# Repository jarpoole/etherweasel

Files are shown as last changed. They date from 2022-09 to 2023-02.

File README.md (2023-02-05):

# EtherWeasel

A proof-of-concept for a hardware man-in-the-middle attack on an Ethernet network. For demonstration purposes this repository provides an implementation of a DNS cache poisoning attack which can edit DNS requests and responses in realtime to trick web clients into connecting to the wrong ip addresses.

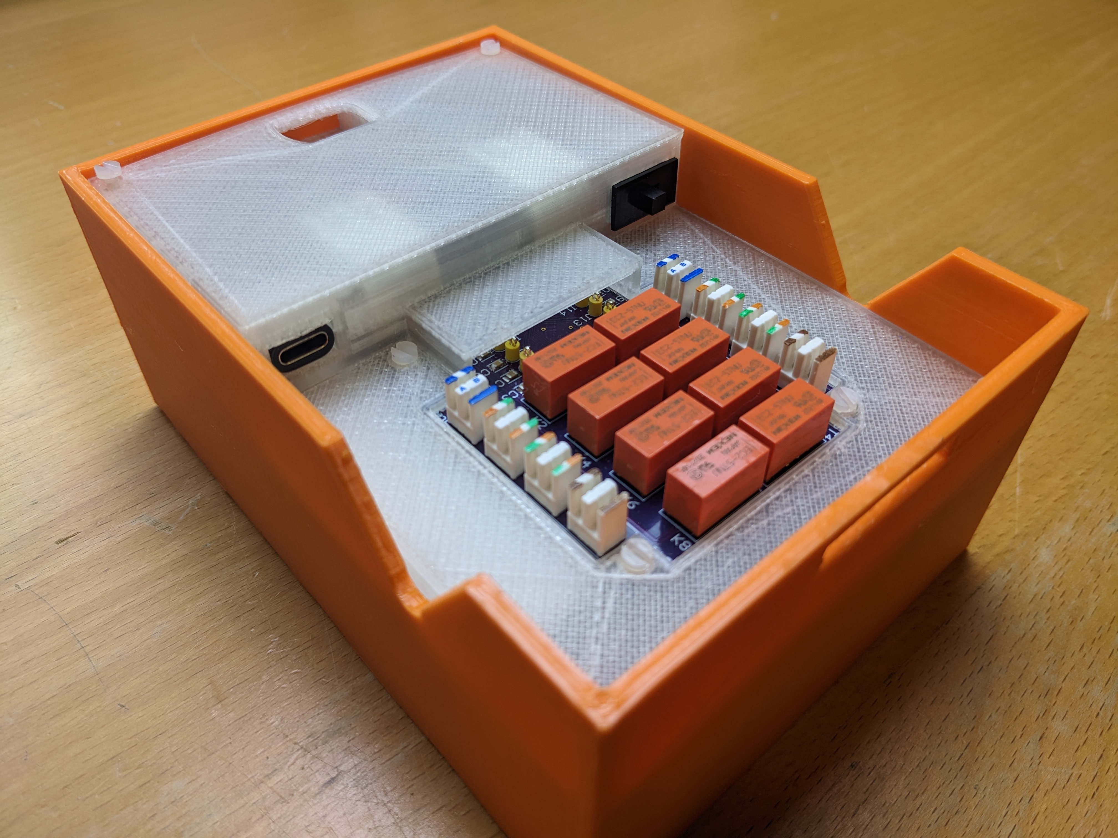
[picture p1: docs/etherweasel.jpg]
etherweasel


## Video

Watch the video that goes with this repository for a quick demonstration of what EtherWeasel can do:
https://www.youtube.com/watch?v=TK0TTOAR--U

## Features

- Battery-operated
- Support for Gigabit Ethernet
- Remotely operated
- Friendly user-interface

## Inspiration

This project was inspired by the excellent work of Van Albert and Banks at DEFCON 23. I highly recommend watching their presentation [here](https://www.youtube.com/watch?v=RoOqznZUClI) and checking out their [GitHub repository](https://github.com/ervanalb/lens).

## Software Limitations

- No support for [DNSSEC](https://en.wikipedia.org/wiki/Domain_Name_System_Security_Extensions) (DNS Security Extensions)
- No support for [DoH](https://en.wikipedia.org/wiki/DNS_over_HTTPS) (DNS over HTTPS)
- No support for [DoT](https://en.wikipedia.org/wiki/DNS_over_TLS) (DNS over TLS)
- No support for [DANE](https://en.wikipedia.org/wiki/DNS-based_Authentication_of_Named_Entities)

## Hardware Limitations

- Insertion into a Gigabit Ethernet network causes momentary disruption. As far as I can tell there are 2 problems (there could be more, the 802.3 spec is really long). See [802.3-2018](https://ieeexplore.ieee.org/stamp/stamp.jsp?tp=&arnumber=8457469).

  1. `MDI/MDI-X`: A process where both interfaces figure out which twisted pairs are connected to what and if any of the pairs have their polarity flipped. Clause 40.4.4 on pg1639 has more details. If the two MitM interfaces are rapidly inserted, how would they know what MDI/MDI-X configuration to use? This information might be available in the FLP transmissions but even if it was these only happen every 16ms so the MitM interfaces would find out too late.

  2. `Auto-negotiation`: In addition to the dimensions of speed (10mb, 100mb, 1000mb), duplex (full, half) and port type (single, multi) which EtherWeasel might just guess, Gigabit Ethernet requires the two interfaces negotiate who is master and who is slave, where the slave will perform clock recovery. This is covered in clause 28 generally and clause 40.5 for Gigabit Ethernet specifically. If two MITM interfaces are inserted, how would they know to take the role of master of slave without triggering negotiation? Maybe Etherweasel could always assume slave, perform clock recovery and then wait 16ms for the next FLP and the clock wouldn't drift too much without a master? This aspect requires a lot more investigation.

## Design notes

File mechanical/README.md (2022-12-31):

# Mechanical

## Design

Source file is `model.f3d` and was created with [Fusion 360](https://www.autodesk.com/products/fusion-360/personal-download).

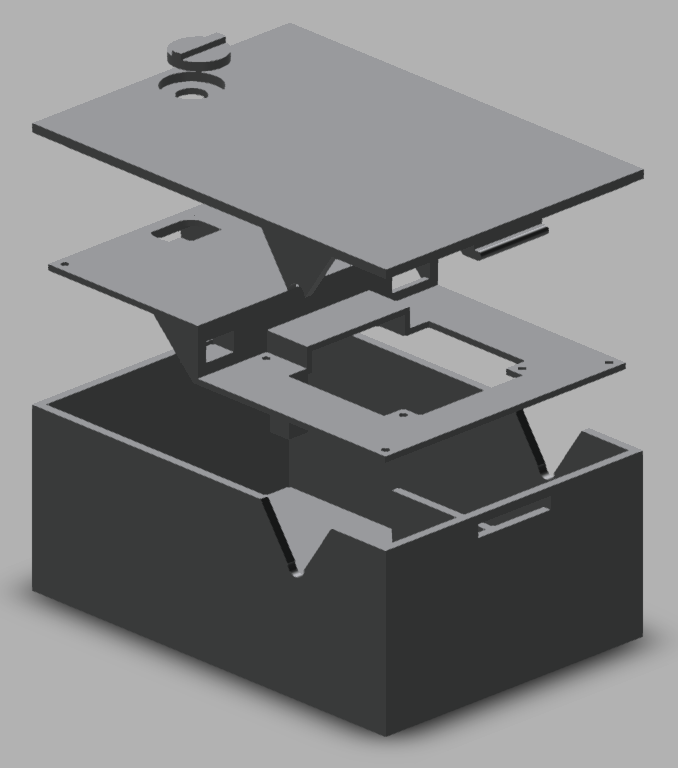
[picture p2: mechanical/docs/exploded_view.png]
exploded_view


## Assembled

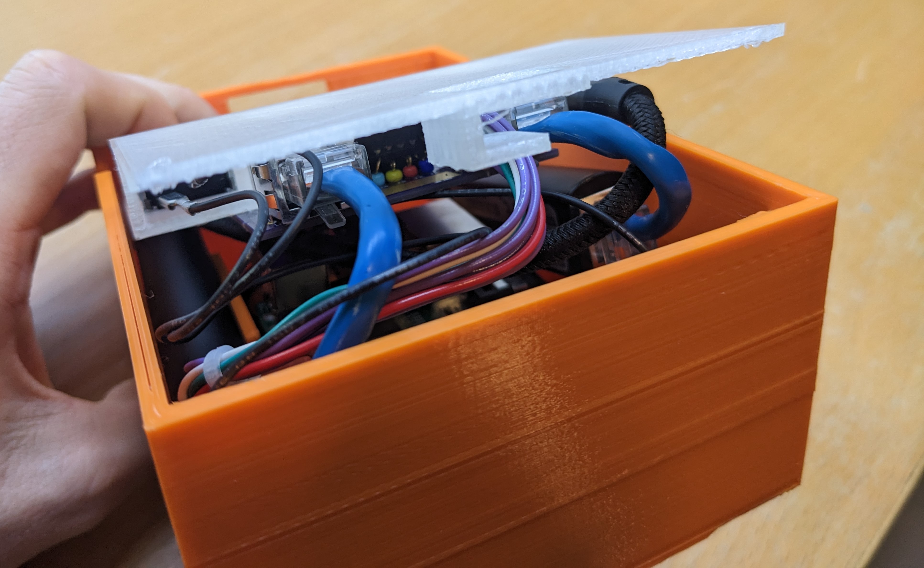
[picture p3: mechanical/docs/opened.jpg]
opened

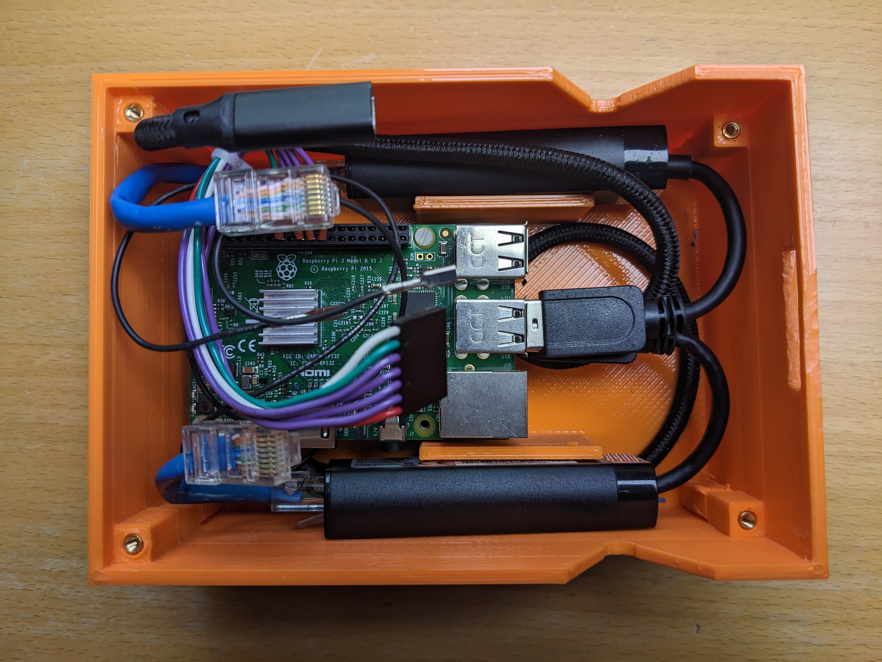
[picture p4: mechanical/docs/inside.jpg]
inside


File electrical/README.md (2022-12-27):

## Switching Board

The switching board consists of 8 latching relays and a low-side 8-channel relay driver with a SPI interface. We opted not to use RF relays because they are expensive. Because latching relays require 2 channels of control each (one to set, one to reset), they are driven in pairs. Punchdown connectors on both sides allow for rapid covert installation (shown in the picture). See the BOM for more details.

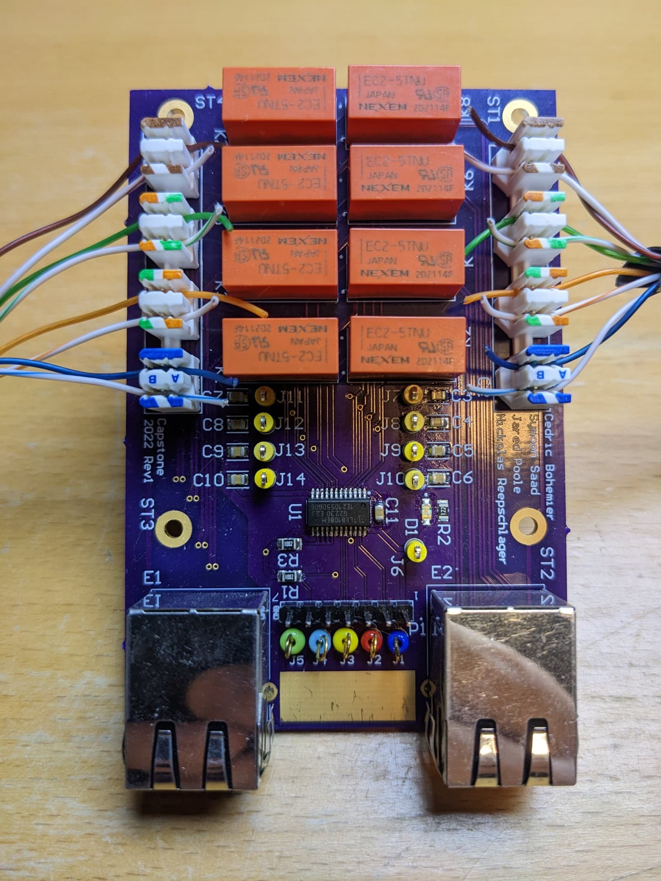
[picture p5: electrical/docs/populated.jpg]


This switching board was designed using Altium Designer 23. If you wish to open the source files, you can get a viewer license for free [here](https://www.altium.com/documentation/altium-designer/viewer-license).

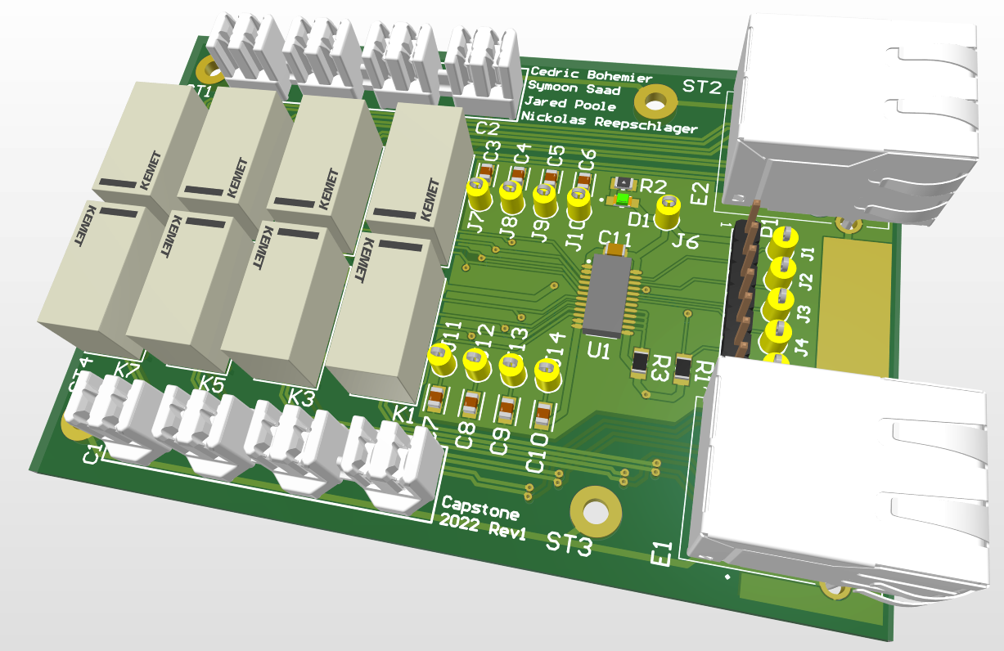
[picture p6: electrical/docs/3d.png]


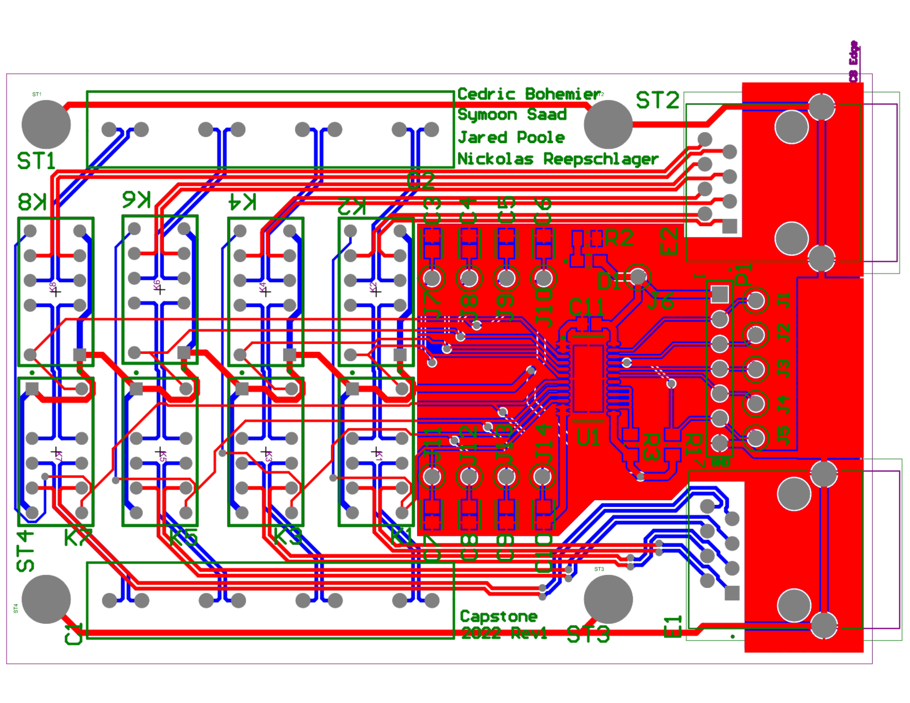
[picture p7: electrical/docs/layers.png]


We elected to manufacture with [OSHpark](https://oshpark.com/) as they have excellent shipping options to Canada. Likely you will want to regenerate the gerber files and do a DRC again for a different manufacturer.

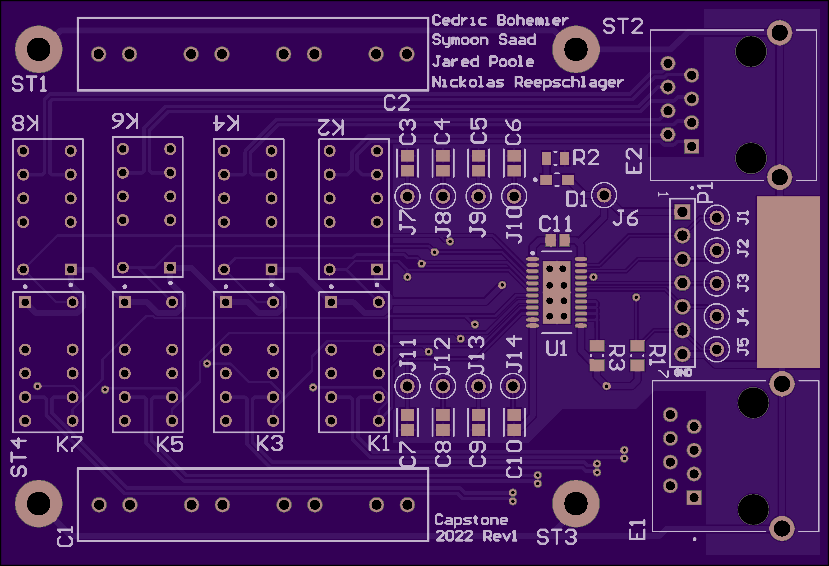
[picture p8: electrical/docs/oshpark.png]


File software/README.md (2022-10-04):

# Dependencies

xhost: `apt install x11-xserver-utils`

# Architecture

The overall architecture of the test suite is given in the block diagram below.

- Networking is in yellow
- Applications are in red
- Docker is in blue

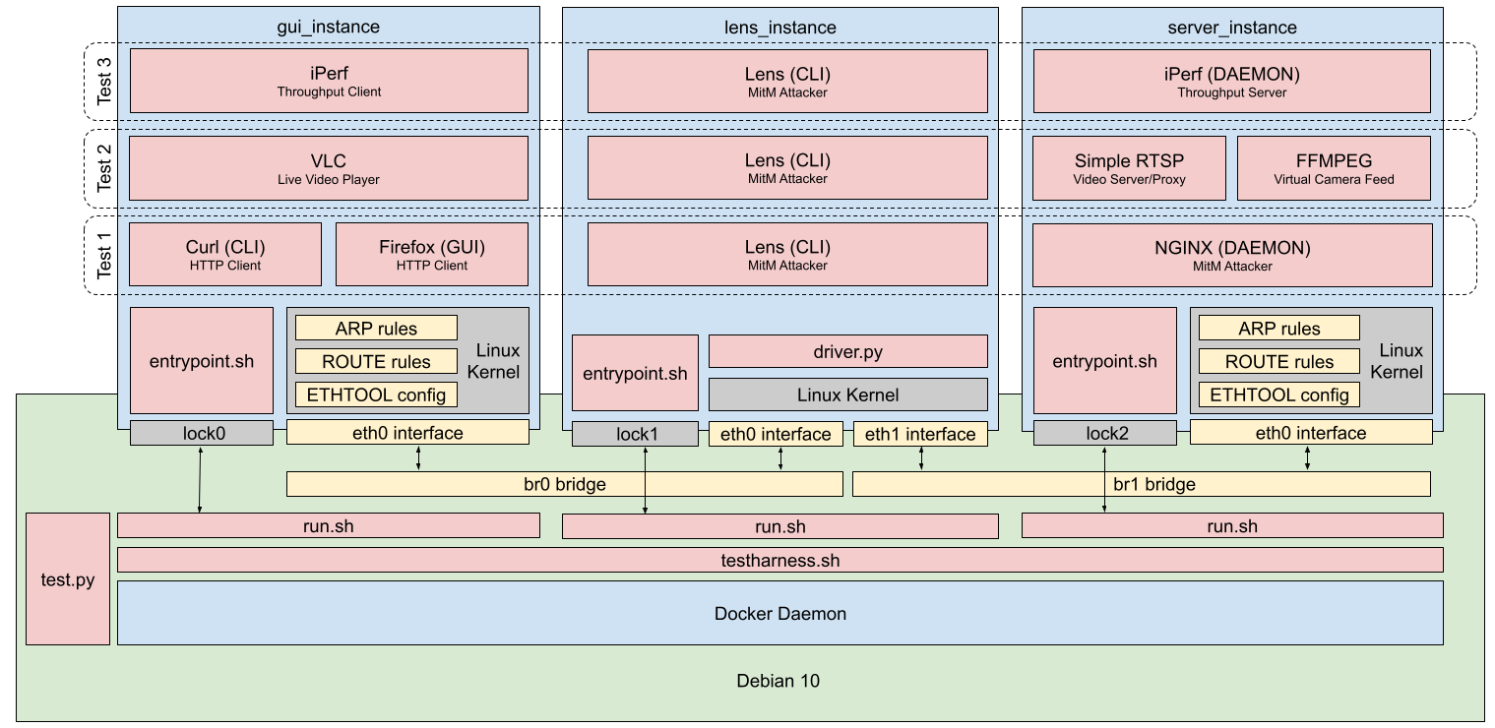
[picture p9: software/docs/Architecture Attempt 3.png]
Architecture


# HTTP Modification Demo

## 1. Launch Terminals

Three interactive shells are required for a full demonstration.

- Leftmost shell will be for a `gui_instance` container
- Middle shell will be for a `lens_instance` container
- Rightmost shell will be for `server_instance` container

## 2. Start Test Harness

Start the test harness using the `testharness.sh` wrapper script.

```bash
sudo ./testharness.sh http
```

## 3. Confirm that Containers Have started

Confirm that all three containers listed below are running.

- `viewer_instance`
- `camera_instance`
- `lens_instance`

## 4. Attach to Other Containers

The middle shell should already be attached to a `lens_instance` container.

In the leftmost shell, attach to `gui_instance`.

```bash
sudo docker container attach gui_instance
```

In the rightmost shell, attach to `server_instance`.

```bash
sudo docker container attach server_instance
```

## 5. Load the Website

Within the leftmost shell inside the container, load a website from the server.

```bash
firefox -private 192.168.0.2
```

Observe that modification should have occured. To confirm, place the driver back into passive mode to confirm. Within the middle shell inside the container run:

```bash
driver passive
```

# Automated Testing

Start the test harness using the automated test contol script `test.py`. To save time the script can either generate results and save them to a temp file with

```bash
sudo ./test.py --save
```

Or load results from a temp file and generate the associated plots.

```bash
sudo ./test.py --load
```

# Other Commands

## Raw capture with TCPdump

To generate packets on a specific interface, either cURL or ping can be used.

```bash
curl --interface eth0 localhost:80
ping -I eth0 localhost:80
```

To capture packets on an interface, use TCPdump.

```bash
tcpdump -e -n -i -vvv -xx eth0
sudo tcpdump -e -n -vvv -xx -w cap.hex -i eth0
```

Hexdump can be used to load captures which were previously saved.

```bash
hexdump -C cap.hex
```

## Download a website

Use `wget` to pull a servable copy of the website recursively.

```bash
wget -k -H -E -p -nd --no-parent -e robots=off https://en.wikipedia.org/wiki/Man-in-the-middle_attack
```

Likely this will result in file names/paths which contain characters like ? which are invalid on windows and should not be commited to git. Therefore zip the resulting website by navigating into the folder and running:

```
tar -czvf ../payload.tar *
```

## Extra shells

When attaching multiple times to a docker container, all connections share the same stdin and stdout. To get a second shell to a container, run one of the commands below.

```bash
sudo docker exec -it iperf_instance bash
sudo docker exec -it gui_instance bash
sudo docker exec -it lens_instance bash
sudo docker exec -it server_instance bash
```

## Wireshare

Install wireshark

```bash
sudo apt update
sudo apt install wireshark
```

Note that wireshark required root permissions to capture packets in its default configuration and so should be run with `sudo wireshark` from a new shell.

If there are both public and private ip addresses in the capture, then consider only ones in the ranges of private IPs. 1) 10.0.0.0 to 10.255.255.255 2) 172.16.0.0 to 172.31.255.255 3) 192.168.0.0 to 192.168.255.255

## Other

```
sudo apt-get install python3-matplotlib
```

https://stackoverflow.com/questions/26999595/what-steps-are-needed-to-stream-rtsp-from-ffmpeg

The docker daemon is only accessible to root users by default. We can fix this with the following commands.

```bash
sudo groupadd docker
sudo usermod -aG docker $USER
```

See https://docs.docker.com/engine/install/linux-postinstall/ for more

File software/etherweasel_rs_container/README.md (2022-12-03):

## WSL

### Installation

Install rust

```
sudo apt-get update
sudo apt install build-essential
curl --proto '=https' --tlsv1.2 -sSf https://sh.rustup.rs | sh
```

Install raspberry pi cross-compilation tools

```bash
rustup target add aarch64-unknown-linux-gnu
sudo  apt install gcc-aarch64-linux-gnu
```

Using cross

```
cargo install cross --git https://github.com/cross-rs/cross
```

Install sshpass

```bash
sudo apt install sshpass
```

Install a new raspberry pi image using `Raspberry Pi OS lite 64bit`, preferably using the raspberry Pi imager so that ssh can be enabled.
update vim and install dig

```bash
sudo apt install vim
sudo apt-get install dnsutils
```

add a static ip by adding the following lines to `/etc/dhcpcd.conf`

```bash
interface eth0
static ip_address=192.168.100.15/24
static routers=192.168.100.1
static domain_name_servers=192.168.100.1
```

Install pcap

```
sudo apt install libpcap-dev
```

Enable SPI

```
sudo raspi-config
sudo reboot
```

Then select (3) Interface options, SPI and select enable. If after a reboot the spi interfaces still don't show up in `/dev` then try
adding `dtparam=spi=on` to `/boot/config.txt` and reboot again.

```bash

```

### Build

```
cargo build
```

### Run

Most development should be done within the Docker container so that key dependencies are available.

```bash
sudo ./run.sh --interactive -- test
```

The build can also be run directly on the host machine

```bash
cargo run
```

To test that the rest API is running, make `GET` request using `curl` on the `/ping` endpoint

```bash
curl -I localhost:3000/ping
```

### Test

Basic API requests can be made using cURL

```bash
curl localhost:3000/mode -X POST -vv -d '{ "mode": "active" }' --header "Content-Type: application/json"
```

## Dependencies

Add a new dependency using cargo

```bash
cargo add my_dep
```

## Useful information

## Remote

1. Install the `Remote - SSH` extension on your local dev machine (` ms-vscode-remote.remote-ssh`)
2. Install vscode on the remote server with snap `snap install --classic code`
3. Install openSSH and configure a static IP address on the server
4. On the far left in local vscode, select `Remote explorer` and add a new `SSH Target`
5. Connect to the new SSH target by clicking the `Connect to host in new window button` and wait for vscode to configure everything

https://stackoverflow.com/questions/14774668/what-is-raw-socket-in-socket-programming

socket(AF_INET,RAW_SOCKET,...) means L3 socket , Network Layer Protocol = IPv4
socket(AF_IPX,RAW_SOCKET,...) means L3 socket , Network Layer Protocol = IPX
socket(AF_INET6,RAW_SOCKET,...) means L3 socket , Network Layer Protocol=IPv6
socket(AF_PACKET,RAW_SOCKET,...) means L2 socket , Data-link Layer Protocol= Ethernet

https://github.com/dbcfd/rs-af_packet

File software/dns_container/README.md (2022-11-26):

Attach to the container

```bash
sudo docker container attach alice_dns_instance
```

To query against the bind server

```bash
dig @192.168.0.2 sub1.example.local +noedns
```

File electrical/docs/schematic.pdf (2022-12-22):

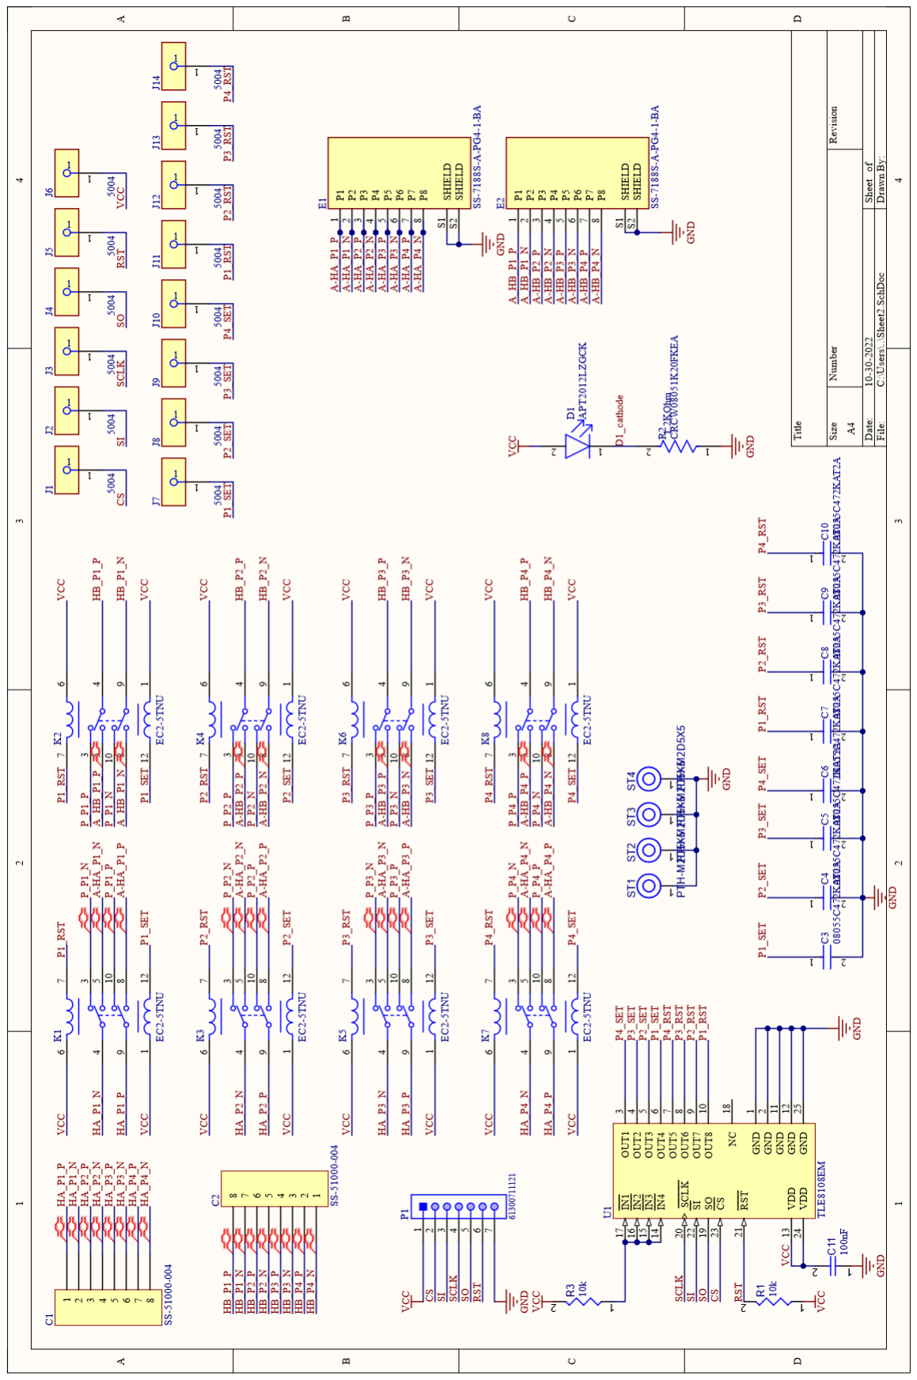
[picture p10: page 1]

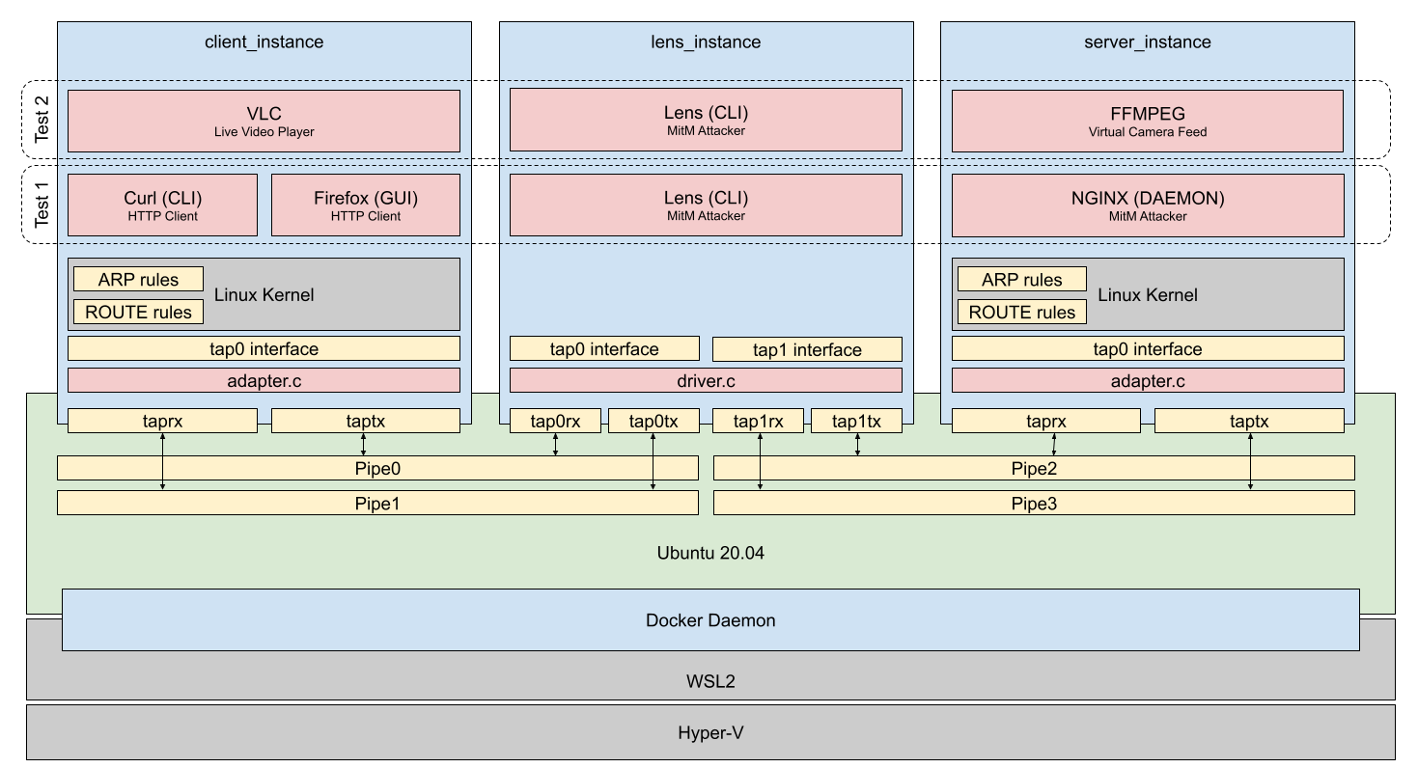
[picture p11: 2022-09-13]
software/docs/Architecture Attempt 1.png

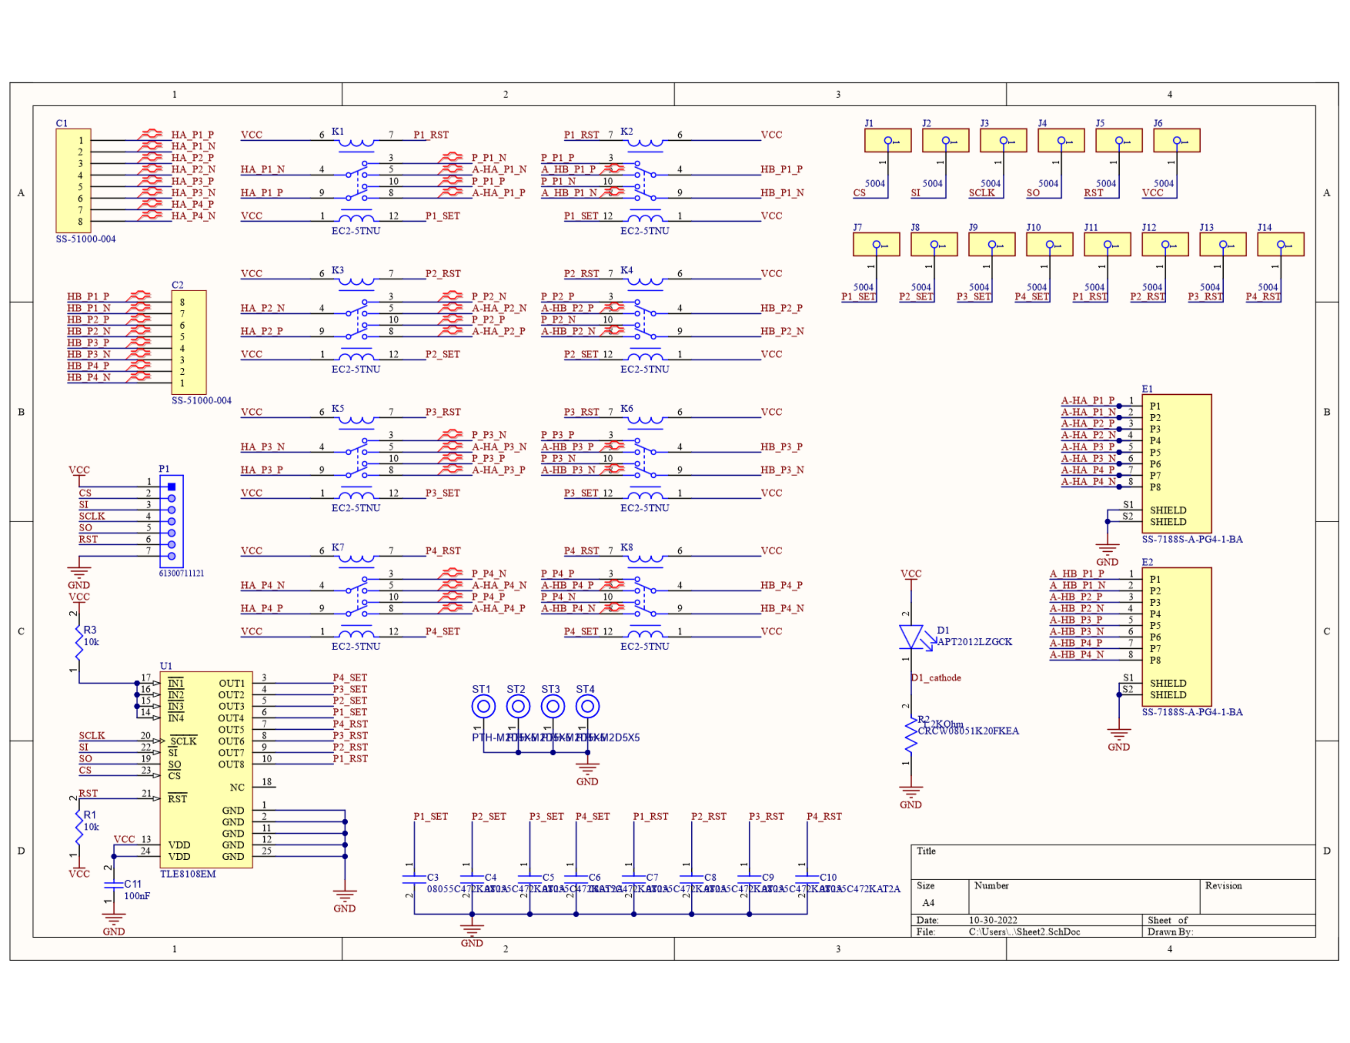
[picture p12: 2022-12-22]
electrical/docs/schematic.png

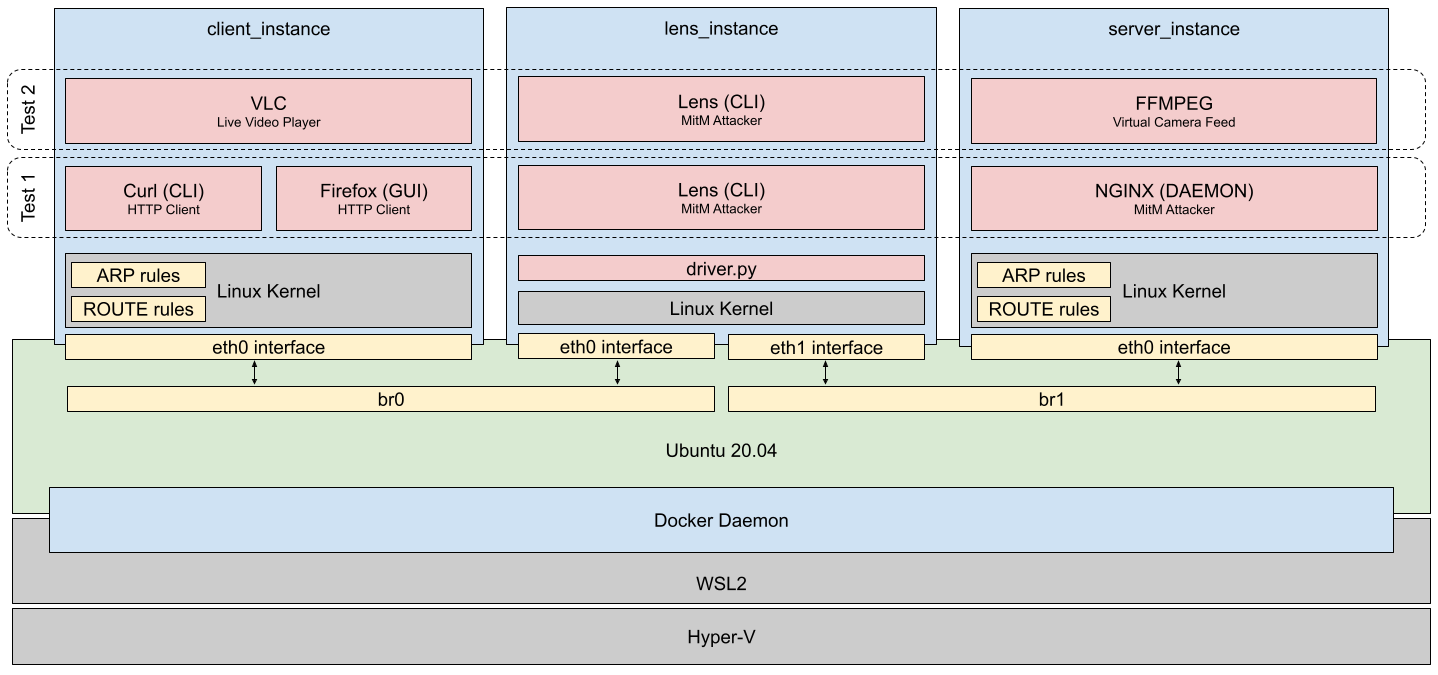
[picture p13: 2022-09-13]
software/docs/Architecture Attempt 2.png

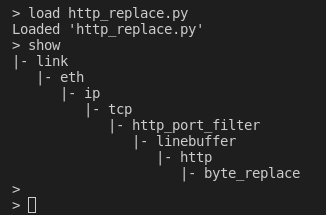
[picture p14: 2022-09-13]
software/docs/Lens HTTP Replace Graph.png

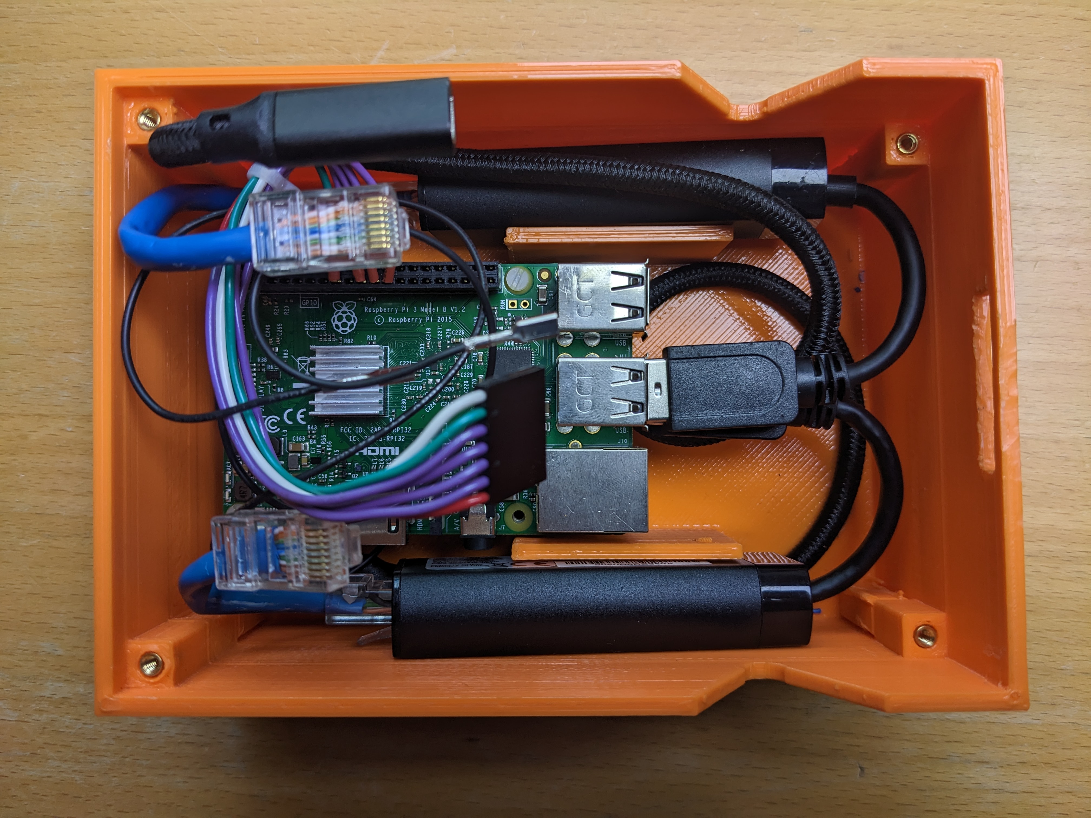
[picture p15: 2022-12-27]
docs/etherweasel_inside.jpg

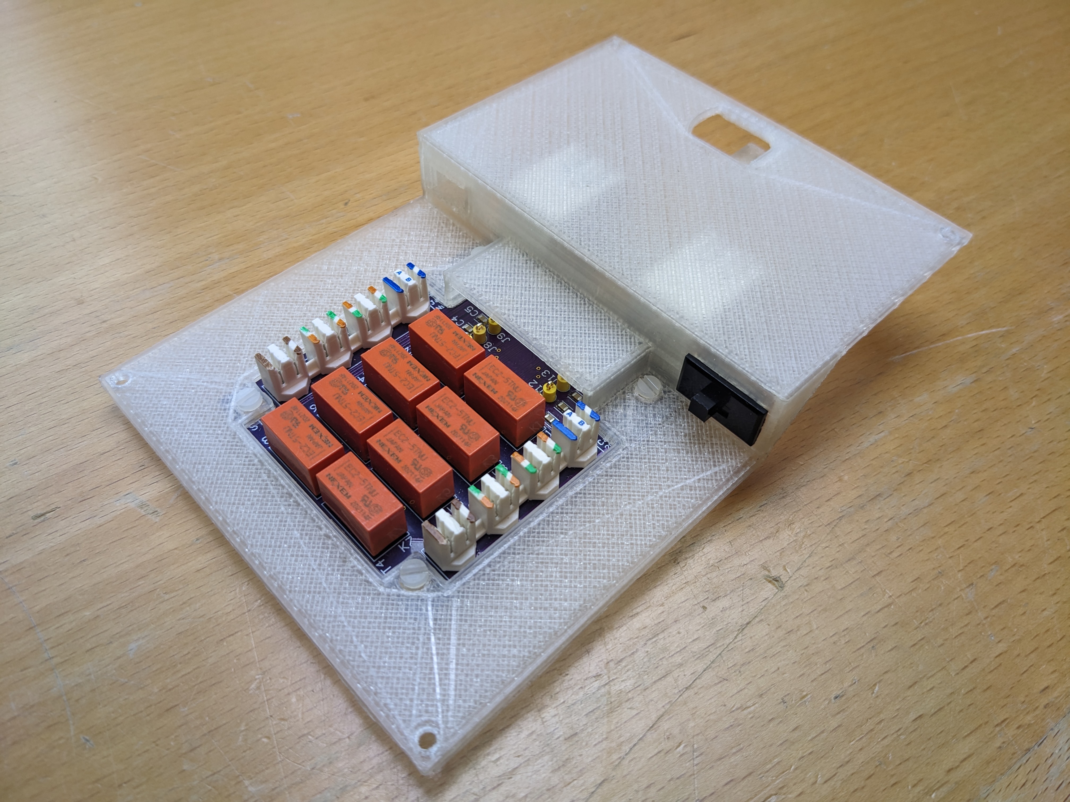
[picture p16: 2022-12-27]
docs/etherweasel_plate.jpg

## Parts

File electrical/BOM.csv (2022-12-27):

Comment | Description | Designator | LibRef | Quantity | Footprint
SS-51000-004 | Stewart Connector, Internal Part #: SS-51000-004 | C1, C2 | CMP-002-00075-4 | 2 | SS-51000-004-Footprint-1
08055C472KAT2A | General Purpose Ceramic Capacitor, 0805, 4.7nF, 10%, X7R, 0.15, 50V | C3, C4, C5, C6, C7, C8, C9, C10 | CMP-1036-03594-3 | 8 | FP-0805-L_2_01_0_2-W_1_25-IPC_B
Capacitor 100 nF +/-10% 50 V 0805 | Chip Capacitor, 100 nF, +/- 10%, 50 V, 0805 (2012 Metric) | C11 | CMP-001-00018-6 | 1 | CAPC2013X95X50LL10T25
APT2012LZGCK | LED GREEN CLEAR 2SMD | D1 | CMP-44529-000065-1 | 1 | FP-APT2012LZGCK-MFG
SS-7188S-A-PG4-1-BA | Conn Modular Jack F 8 POS 1.27mm Solder RA Thru-Hole 8 Terminal 1 Port | E1, E2 | CMP-002-00072-1 | 2 | SS-7188S-A-PG4-1-BA-Footprint-1
5004 | PC TEST POINT MINIATURE YELLOW | J1, J2, J3, J4, J5, J6, J7, J8, J9, J10, J11, J12, J13, J14 | CMP-2000-05575-2 | 14 | FP-5004-MFG
EC2-5TNU | RELAY GEN PURPOSE DPDT 2A 5VDC | K1, K2, K3, K4, K5, K6, K7, K8 | CMP-03195-000012-1 | 8 | FP-EC2-5TNU-MFG
61300711121 | THT Vertical Pin Header WR-PHD, Pitch 2.54 mm, Single Row, 7 pins | P1 | CMP-1502-01074-1 | 1 | 61300711121
Resistor 10k +/-1% 0805 125 mW | Chip Resistor, 10 KOhm, +/- 1%, 125 mW, -55 to 155 degC, 0805 (2012 Metric) | R1, R3 | CMP-009-00018-5 | 2 | RESC2013X50X35ML15T15
CRCW08051K20FKEA | RES Thick Film, 1.2k?, 1%, 0.125W, 100ppm/°C, 0805 | R2 | CMP-2001-03607-2 | 1 | FP-CRCW0805-e3-MFG
PTH-M2D5X5 | M2 PTH (2.5mm), 5mm pad | ST1, ST2, ST3, ST4 | CMP-00028-00004-2 | 4 | PTH-M2D5X5
TLE8108EM | Smart 8 Channel Low Side Relay Driver with SPI Interface with Limitation Over-Current Protection, -40 to 150 degC, PG-SSOP-24-4, Reel, Green | U1 | CMP-1097-00013-1 | 1 | INF-PG-SSOP-24-4_L

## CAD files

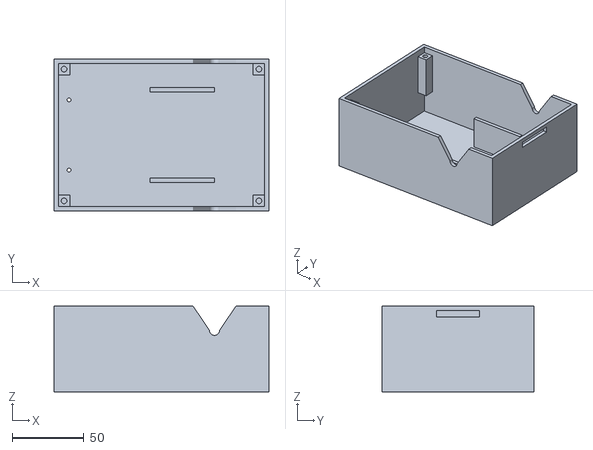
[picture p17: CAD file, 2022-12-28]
mechanical/case.stl
150.0 x 106.0 x 60.0

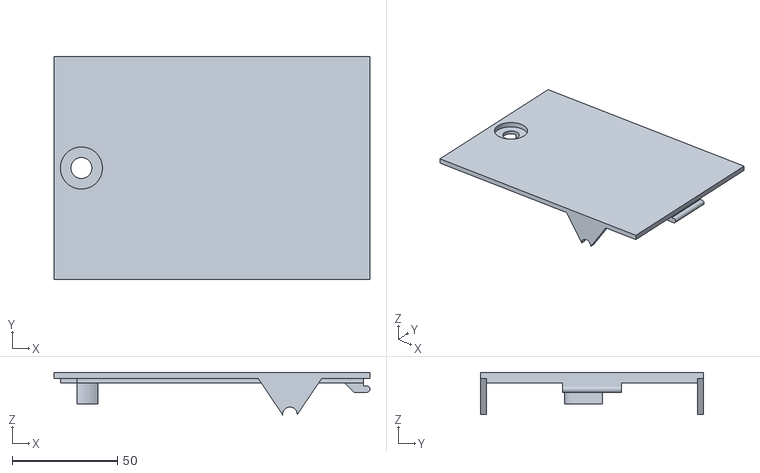
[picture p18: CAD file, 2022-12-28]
mechanical/lid.stl
150.0 x 106.0 x 20.1

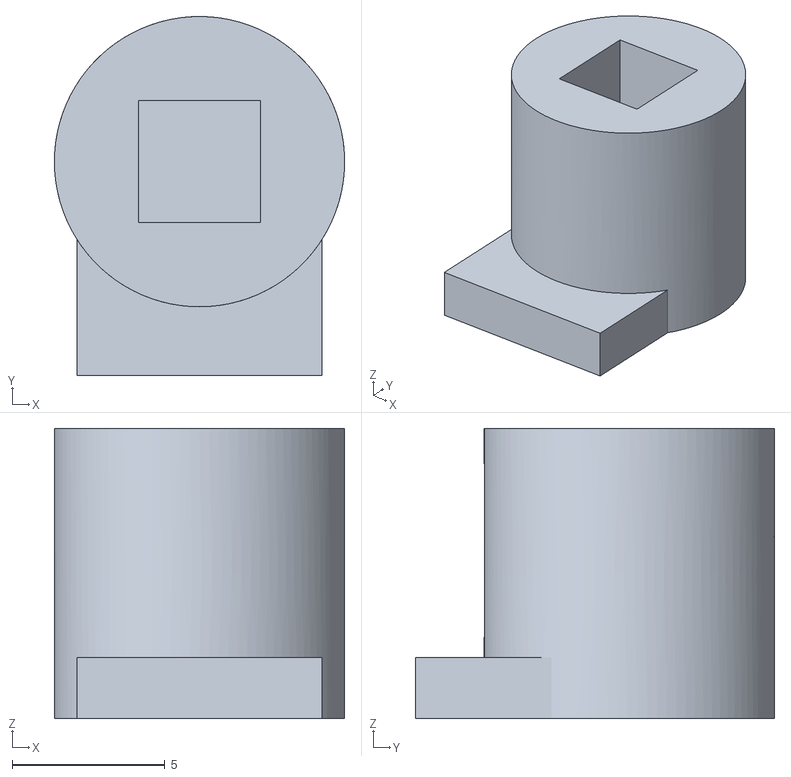
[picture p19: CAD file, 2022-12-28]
mechanical/lock_bottom.stl
9.50 x 11.8 x 9.50

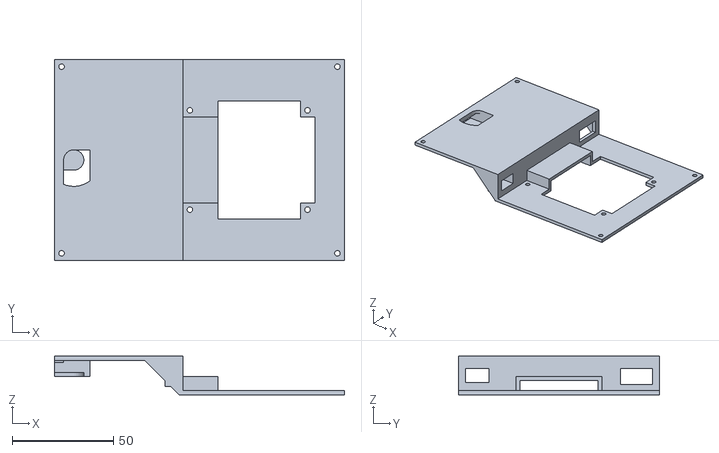
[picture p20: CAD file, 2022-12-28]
mechanical/insert.stl
143.0 x 99.0 x 19.0

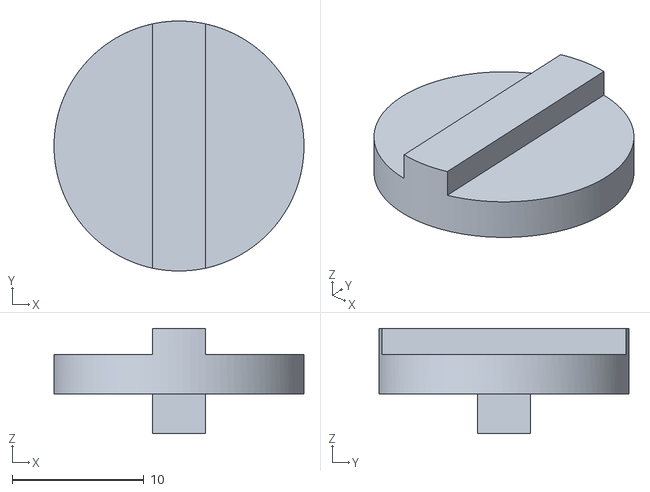
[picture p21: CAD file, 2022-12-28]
mechanical/lock_top.stl
19.0 x 19.0 x 8.00

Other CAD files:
mechanical/model.f3d

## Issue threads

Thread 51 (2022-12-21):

Hardware/Schematics?

EvergreenCartoons, 2022-12-21:
Got to here from your awesome demo video, was wondering if you intended on open sourcing the hardware schematic as well as the software side?

I'd love to do some experimenting with this myself at some point, its an awesome demonstration of what an attacker can do with "access to an exposed ethernet cable", and I suspect the hardware side will be *very* enlightening.

jarpoole, 2022-12-28:
Yep! Exams and holidays had me a little busy and I still haven't uploaded all the mechanical files but see the electrical folder for schematics, layout and BOM!

Closed 2022-12-28.

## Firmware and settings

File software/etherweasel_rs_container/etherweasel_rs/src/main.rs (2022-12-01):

mod attack;
mod driver;

use addr::parse_dns_name;
use attack::{attack::Attack, sniff::Sniff};
use axum::{
    extract::{Path, Query},
    http::StatusCode,
    response::IntoResponse,
    routing::{get, post},
    Extension, Json, Router,
};
use clap::{Parser, ValueEnum};
use dashmap::DashMap;
use driver::{
    docker_driver::{DockerDriver, DockerDriverConfig},
    driver::{DriverGuard, DriverMode},
    hardware_driver::HardwareDriver,
    mock_driver::MockDriver,
};
use futures::stream::TryStreamExt;
use libc;
use rtnetlink::{new_connection, Error};
use serde::{de::Error as DeError, Deserialize, Deserializer, Serialize};
use std::collections::HashMap;
use std::net::{Ipv4Addr, SocketAddr};
use std::sync::Arc;
use sysinfo::{CpuExt, CpuRefreshKind, NetworkData, NetworkExt, RefreshKind, System, SystemExt};
use tokio::sync::Mutex;
use tower_http::cors::CorsLayer;
use tracing::{debug, error, info, warn, Level};
use uuid::Uuid;

use crate::attack::dns::Dns;

const SPI_INTERFACE: &str = "/dev/spidev0.0";

// Docker mock driver devices
const DOCKER_ETHERNET_A: &str = "ethmitmA";
const DOCKER_ETHERNET_B: &str = "ethmitmB";
const DOCKER_INTERFACE_A: &str = "tapA";
const DOCKER_INTERFACE_B: &str = "tapB";
const DOCKER_BRIDGE_A: &str = "brA";
const DOCKER_BRIDGE_B: &str = "brB";
const DOCKER_BRIDGE_AB: &str = "brAB";

// Notice we listen on all interfaces here (0.0.0.0) instead
// of the standard localhost (127.0.0.1) because we would like
// the server to be accessible from the outside network
const API_PORT: u16 = 3000;
const API_ADDRESS: [u8; 4] = [0, 0, 0, 0];

#[derive(Debug, Clone, ValueEnum)]
enum Mode {
    ACTIVE,
    PASSIVE,
}

#[derive(Debug, Clone, ValueEnum)]
enum Driver {
    HARDWARE,
    MOCK,
    DOCKER,
}
#[derive(Parser)]
struct Cli {
    #[arg(short, long, default_value = "eth0,wlan0", value_delimiter = ',')]
    interfaces: Vec<String>,
    #[arg(
        short,
        long,
        default_value_t = Driver::HARDWARE,
        value_enum
    )]
    driver: Driver,
    #[arg(
        short,
        long,
        default_value_t = Mode::PASSIVE,
        value_enum
    )]
    mode: Mode,
    #[arg(
        short,
        long,
        help = "perform initial hardware discovery, configuration and exit"
    )]
    configure: bool,
    #[arg(short, long, action = clap::ArgAction::Count, help = "set the logging level")]
    verbose: u8,
}

#[derive(Clone)]
struct EthInterfaces(String, String);

type Attacks = Arc<DashMap<Uuid, Mutex<Box<dyn Attack + Send + Sync>>>>;

#[tokio::main(flavor = "multi_thread", worker_threads = 4)]
async fn main() {
    // Handle CLI arguments
    let args = Cli::parse();
    let driver_guard: DriverGuard = Arc::new(Mutex::new(match args.driver {
        Driver::MOCK => Box::new(MockDriver::new()),
        Driver::DOCKER => Box::new(DockerDriver::new(DockerDriverConfig {
            ethernet_a: DOCKER_ETHERNET_A,
            ethernet_b: DOCKER_ETHERNET_B,
            interface_a: DOCKER_INTERFACE_A,
            interface_b: DOCKER_INTERFACE_B,
            bridge_a: DOCKER_BRIDGE_A,
            bridge_b: DOCKER_BRIDGE_B,
            bridge_ab: DOCKER_BRIDGE_AB,
        })),
        Driver::HARDWARE => Box::new(HardwareDriver::new(SPI_INTERFACE)),
    }));
    let driver_mode = match args.mode {
        Mode::PASSIVE => DriverMode::PASSIVE,
        Mode::ACTIVE => DriverMode::ACTIVE,
    };
    let verbosity = match args.verbose {
        0 => Level::INFO,
        1 => Level::DEBUG,
        _ => Level::TRACE,
    };
    let eth_interfaces = EthInterfaces(
        String::from(&args.interfaces[0]),
        String::from(&args.interfaces[1]),
    );

    // Configure logging
    tracing_subscriber::fmt().with_max_level(verbosity).init();

    // Log the entire configuration
    debug!("mode: {:?}", args.mode);
    debug!("driver: {:?}", args.driver);
    debug!(
        "interface A: {:?}, interface B: {:?}",
        eth_interfaces.0, eth_interfaces.1
    );
    if args.interfaces.len() > 2 {
        warn!("Extra interfaces will be ignored");
    }
    info!("etherweasel_rs running...");

    // Configure the driver
    if set_mode(driver_guard.clone(), driver_mode).await.is_err() {
        error!("Failed to change driver mode");
    }

    // Configure system monitoring
    let sys_info_guard = Arc::new(Mutex::new(System::new_with_specifics(
        RefreshKind::new()
            .with_cpu(CpuRefreshKind::everything())
            .with_memory()
            .with_networks()
            .with_networks_list(),
    )));

    // Configure interfaces
    set_promiscuous(eth_interfaces.0.as_str())
        .await
        .expect("failed to set promiscuous mode");
    set_promiscuous(eth_interfaces.1.as_str())
        .await
        .expect("failed to set promiscuous mode");

    // Create a map to store the state of the backend dns attacks
    let attacks: Attacks = Arc::new(DashMap::new());

    // Configure API
    let app = Router::new()
        .route("/ping", get(ping))
        .route("/mode", get(get_mode_handler).post(set_mode_handler))
        .route("/performance", get(get_performance_stats))
        .route("/networking", get(get_networking))
        .route("/info", get(get_device_info))
        .route("/attack", post(create_attack_handler))
        .route("/attacks", get(get_attack_ids_handler))
        .route(
            "/attack/:id",
            get(get_attack_handler).delete(delete_attack_handler),
        )
        .route("/logs/:id", get(get_logs_handler))
        .layer(CorsLayer::very_permissive())
        .layer(Extension(driver_guard))
        .layer(Extension(eth_interfaces))
        .layer(Extension(attacks))
        .layer(Extension(sys_info_guard));
    let addr = SocketAddr::from((API_ADDRESS, API_PORT));
    axum::Server::bind(&addr)
        .serve(app.into_make_service())
        .await
        .unwrap();
    info!("HTTP API available on {}", addr);
}

async fn ping() -> impl IntoResponse {
    StatusCode::OK
}

#[derive(Deserialize, Debug)]
struct SetMode {
    mode: String,
}

#[axum::debug_handler]
async fn set_mode_handler(
    Extension(driver): Extension<DriverGuard>,
    Json(payload): Json<SetMode>,
) -> impl IntoResponse {
    match DriverMode::from(&payload.mode) {
        Ok(mode) => match set_mode(driver, mode).await {
            Ok(()) => StatusCode::OK,
            Err(()) => StatusCode::INTERNAL_SERVER_ERROR,
        },
        Err(()) => StatusCode::BAD_REQUEST,
    }
}
async fn set_mode(driver_guard: DriverGuard, mode: DriverMode) -> Result<(), ()> {
    debug!("Attempting to set mode to {:?}", mode);
    let mut driver = driver_guard.lock().await;
    match driver.set_mode(mode).await {
        Ok(()) => {
            debug!("Successfully set mode to {:?}", mode);
            Ok(())
        }
        Err(_) => {
            error!("Failed to set mode to {:?}", mode);
            Err(())
        }
    }
}

#[axum::debug_handler]
async fn get_mode_handler(Extension(driver_guard): Extension<DriverGuard>) -> impl IntoResponse {
    match get_mode(driver_guard).await {
        Ok(mode) => (StatusCode::OK, Json(mode)).into_response(),
        Err(()) => StatusCode::INTERNAL_SERVER_ERROR.into_response(),
    }
}
async fn get_mode(driver_guard: DriverGuard) -> Result<DriverMode, ()> {
    debug!("Attempting to get mode");
    let driver = driver_guard.lock().await;
    match driver.get_mode().await {
        Ok(mode) => {
            debug!("Successfully got mode {:?}", mode);
            Ok(mode)
        }
        Err(_) => {
            error!("Failed to get mode");
            Err(())
        }
    }
}

#[derive(Serialize)]
#[serde(rename_all = "camelCase")]
struct PerformanceStats {
    free_memory: u64,
    total_memory: u64,
    cpu_frequency: u64,
    cpu_usage: Vec<f32>,
}

#[axum::debug_handler]
async fn get_performance_stats(
    Extension(sys_info_guard): Extension<Arc<Mutex<System>>>,
) -> impl IntoResponse {
    let mut sys_info = sys_info_guard.lock().await;
    sys_info.refresh_all();
    (
        StatusCode::OK,
        Json(PerformanceStats {
            free_memory: sys_info.free_memory(),
            total_memory: sys_info.total_memory(),
            cpu_frequency: sys_info.global_cpu_info().frequency() * 1000000,
            cpu_usage: sys_info.cpus().iter().map(|cpu| cpu.cpu_usage()).collect(),
        }),
    )
}

#[derive(Serialize)]
#[serde(rename_all = "camelCase")]
struct HostNetworking {
    interface: String,
    mac_address: Option<String>,
    connected: bool,
    // RX statistics
    rx_bytes: u64,
    rx_packets: u64,
    // TX statistics
    tx_bytes: u64,
    tx_packets: u64,
}

#[derive(Serialize)]
#[serde(rename_all = "camelCase")]
struct Networking {
    alice: HostNetworking,
    bob: HostNetworking,
}

#[axum::debug_handler]
async fn get_networking(
    Extension(sys_info_guard): Extension<Arc<Mutex<System>>>,
    Extension(interfaces): Extension<EthInterfaces>,
) -> impl IntoResponse {
    let mut sys_info = sys_info_guard.lock().await;
    sys_info.refresh_networks();
    let stats: HashMap<&String, &NetworkData> = sys_info.networks().into_iter().collect();
    if let (Some(alice_stats), Some(bob_stats), Ok(alice_link_up), Ok(bob_link_up)) = (
        stats.get(&interfaces.0),
        stats.get(&interfaces.1),
        is_up(&interfaces.0).await,
        is_up(&interfaces.1).await,
    ) {
        (
            StatusCode::OK,
            Json(Networking {
                alice: HostNetworking {
                    interface: interfaces.0,
                    mac_address: None,
                    connected: alice_link_up,
                    rx_bytes: alice_stats.total_received(),
                    rx_packets: alice_stats.total_packets_received(),
                    tx_bytes: alice_stats.total_transmitted(),
                    tx_packets: alice_stats.total_packets_transmitted(),
                },
                bob: HostNetworking {
                    interface: interfaces.1,
                    mac_address: None,
                    connected: bob_link_up,
                    rx_bytes: bob_stats.total_received(),
                    rx_packets: bob_stats.total_packets_received(),
                    tx_bytes: bob_stats.total_transmitted(),
                    tx_packets: bob_stats.total_packets_transmitted(),
                },
            }),
        )
            .into_response()
    } else {
        StatusCode::INTERNAL_SERVER_ERROR.into_response()
    }
}

#[derive(Serialize)]
#[serde(rename_all = "camelCase")]
struct DeviceInfo {
    name: Option<String>,
    os_name: Option<String>,
    os_version: Option<String>,
    kernel_version: Option<String>,
    uptime: u64,
}

#[axum::debug_handler]
async fn get_device_info(
    Extension(sys_info_guard): Extension<Arc<Mutex<System>>>,
) -> impl IntoResponse {
    let mut sys_info = sys_info_guard.lock().await;
    sys_info.refresh_all();
    (
        StatusCode::OK,
        Json(DeviceInfo {
            name: sys_info.host_name(),
            os_name: sys_info.name(),
            os_version: sys_info.os_version(),
            kernel_version: sys_info.kernel_version(),
            uptime: sys_info.uptime(),
        }),
    )
}

async fn set_promiscuous(interface: &str) -> Result<(), Error> {
    let (connection, handle, _) = new_connection().unwrap();
    let task = tokio::spawn(connection);
    let response = handle
        .link()
        .get()
        .match_name(interface.to_string().clone())
        .execute()
        .try_next()
        .await?
        .ok_or(Error::RequestFailed)?;
    handle
        .link()
        .set(response.header.index)
        .promiscuous(true)
        .execute()
        .await?;
    task.abort();
    Ok(())
}

async fn is_up(interface: &str) -> Result<bool, Error> {
    let (connection, handle, _) = new_connection().unwrap();
    let task = tokio::spawn(connection);
    let response = handle
        .link()
        .get()
        .match_name(interface.to_string().clone())
        .execute()
        .try_next()
        .await?
        .ok_or(Error::RequestFailed)?;
    task.abort();
    Ok(response.header.flags & libc::IFF_RUNNING as u32 != 0)
}

#[derive(Deserialize, Debug)]
struct DnsAttackConfig {
    #[serde(deserialize_with = "validate_fqdn")]
    fqdn: String,
    ipv4: Ipv4Addr,
    ttl: u32,
    logging: bool,
}

fn validate_fqdn<'de, D>(deserializer: D) -> Result<String, D::Error>
where
    D: Deserializer<'de>,
{
    let string: String = Deserialize::deserialize(deserializer)?;
    match parse_dns_name(&string) {
        Ok(addr) => Ok(addr.as_str().to_owned()),
        Err(_) => Err(DeError::custom("Invalid FQDN")),
    }
}

#[derive(Deserialize, Debug)]
struct SniffAttackConfig {}

#[derive(Deserialize, Debug)]
#[serde(tag = "type", rename_all = "camelCase")]
enum CreateAttack {
    //Dns { config: DnsAttackConfig },
    Sniff { config: SniffAttackConfig },
    Dns { config: DnsAttackConfig },
}

#[derive(Serialize, Debug)]
struct CreateAttackResponse {
    id: Uuid,
}

#[axum::debug_handler]
async fn create_attack_handler(
    Json(payload): Json<CreateAttack>,
    Extension(attacks): Extension<Attacks>,
    Extension(interfaces): Extension<EthInterfaces>,
) -> impl IntoResponse {
    match create_attack(payload, attacks, interfaces) {
        Ok(id) => (StatusCode::CREATED, Json(CreateAttackResponse { id })).into_response(),
        Err(()) => StatusCode::INTERNAL_SERVER_ERROR.into_response(),
    }
}
fn create_attack(
    new_attack: CreateAttack,
    attacks: Attacks,
    interfaces: EthInterfaces,
) -> Result<Uuid, ()> {
    debug!(
        "Attempting to create new attack with config {:?}",
        new_attack
    );
    let uuid = Uuid::new_v4();
    let mut attack: Box<dyn Attack + Send + Sync> = match new_attack {
        CreateAttack::Sniff { config } => Box::new(Sniff {
            interface1: interfaces.0,
            interface2: interfaces.1,
            concurrency: 2,
            tasks: vec![],
        }),
        CreateAttack::Dns { config } => Box::new(Dns {
            interface1_name: interfaces.0,
            interface2_name: interfaces.1,
            fqdn: config.fqdn.to_string(),
            ipv4: config.ipv4,
            ttl: config.ttl,
            logging: config.logging,
            ..Default::default()
        }),
    };
    attack.start();
    attacks.insert(uuid, Mutex::new(attack));
    Ok(uuid)
}

#[derive(Deserialize)]
struct TypeFilter {
    r#type: String,
}

#[axum::debug_handler]
async fn get_attack_ids_handler(
    Extension(attacks): Extension<Attacks>,
    type_filter: Query<TypeFilter>,
) -> impl IntoResponse {
    let attack_type = type_filter.0.r#type;
    (StatusCode::OK, Json(get_attack_ids(attacks, attack_type)))
}
fn get_attack_ids(attacks: Attacks, attack_type: String) -> Vec<Uuid> {
    attacks.iter().map(|el| el.key().to_owned()).collect()
}

#[axum::debug_handler]
async fn get_attack_handler(
    Extension(attacks): Extension<Attacks>,
    Path(id): Path<Uuid>,
) -> impl IntoResponse {
    match get_attack(attacks, id).await {
        Some(attack) => (StatusCode::OK, Json(attack)).into_response(),
        None => StatusCode::NOT_FOUND.into_response(),
    }
}
async fn get_attack(attacks: Attacks, id: Uuid) -> Option<Box<dyn erased_serde::Serialize>> {
    match attacks.get(&id) {
        Some(attack) => Some(attack.value().lock().await.get_config()),
        None => None,
    }
}

#[axum::debug_handler]
async fn delete_attack_handler(
    Path(id): Path<Uuid>,
    Extension(attacks): Extension<Attacks>,
) -> impl IntoResponse {
    match delete_attack(id, attacks).await {
        Ok(()) => StatusCode::OK,
        Err(()) => StatusCode::NOT_FOUND,
    }
}
async fn delete_attack(id: Uuid, attacks: Attacks) -> Result<(), ()> {
    if let Some((_, attack_guard)) = attacks.remove(&id) {
        let mut attack = attack_guard.lock().await;
        attack.stop().map_err(|_| ())
    } else {
        Err(())
    }
}

#[axum::debug_handler]
async fn get_logs_handler(
    Path(id): Path<Uuid>,
    Extension(attacks): Extension<Attacks>,
) -> impl IntoResponse {
    match get_logs(id, attacks).await {
        Ok(logs) => (StatusCode::OK, Json(logs)).into_response(),
        Err(_) => StatusCode::BAD_REQUEST.into_response(),
    }
}

async fn get_logs(id: Uuid, attacks: Attacks) -> Result<Vec<Box<dyn erased_serde::Serialize>>, ()> {
    if let Some(attack_guard) = attacks.get(&id) {
        let attack = attack_guard.lock().await;
        Ok(attack.get_logs())
    } else {
        Err(())
    }
}

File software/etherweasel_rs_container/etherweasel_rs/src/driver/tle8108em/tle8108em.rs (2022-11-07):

use spidev::{SpiModeFlags, Spidev, SpidevOptions, SpidevTransfer};
use std::io;
use tracing::trace;

const TLE8108EM_SPI_SCLK_HZ: u32 = 100000;
const TLE8108EM_SPI_MODE: SpiModeFlags = SpiModeFlags::SPI_MODE_1;

pub enum Channel {
    CH1 = 1,
    CH2 = 2,
    CH3 = 3,
    CH4 = 4,
    CH5 = 5,
    CH6 = 6,
    CH7 = 7,
    CH8 = 8,
}
#[derive(Clone, Copy)]
pub enum ChannelMode {
    CLEAR = 0b00,
    INPUT = 0b01,
    ON = 0b10,
    OFF = 0b11,
}

#[derive(Clone, Copy)]
pub enum ChannelDiag {
    OK = 0b11,
    SCB = 0b10,
    OL = 0b01,
    SCG = 0b00,
}
trait ToInt {
    fn to_int(&self) -> u16;
}
impl ToInt for ChannelMode {
    fn to_int(&self) -> u16 {
        *self as u16
    }
}

type Register<T> = [T; 8];
impl<T> std::ops::Index<Channel> for Register<T> {
    type Output = T;
    fn index(&self, channel: Channel) -> &T {
        self.index(channel as usize - 1)
    }
}
impl<T> std::ops::IndexMut<Channel> for Register<T> {
    fn index_mut(&mut self, channel: Channel) -> &mut T {
        self.index_mut(channel as usize - 1)
    }
}
trait Reset<T> {
    fn reset() -> Register<T>;
}
impl Reset<ChannelMode> for Register<ChannelMode> {
    fn reset() -> Self {
        [
            ChannelMode::OFF,
            ChannelMode::OFF,
            ChannelMode::OFF,
            ChannelMode::OFF,
            ChannelMode::OFF,
            ChannelMode::OFF,
            ChannelMode::OFF,
            ChannelMode::OFF,
        ]
    }
}
impl Reset<ChannelDiag> for Register<ChannelDiag> {
    fn reset() -> Self {
        [
            ChannelDiag::OK,
            ChannelDiag::OK,
            ChannelDiag::OK,
            ChannelDiag::OK,
            ChannelDiag::OK,
            ChannelDiag::OK,
            ChannelDiag::OK,
            ChannelDiag::OK,
        ]
    }
}
trait Pack<T> {
    fn pack(&self) -> BinaryRegister;
}
// TLE8108EM SPI interface is little endian
impl<T: ToInt> Pack<T> for Register<T> {
    fn pack(&self) -> BinaryRegister {
        let mut accumulator: u16 = 0;
        for i in 0..8 {
            accumulator += (self[i].to_int()) << i * 2;
        }
        accumulator.to_be_bytes()
    }
}
type BinaryRegister = [u8; 2];
trait Unpack<T> {
    fn unpack(&self) -> Register<T>;
}
impl Unpack<ChannelDiag> for BinaryRegister {
    fn unpack(&self) -> Register<ChannelDiag> {
        // todo(jarpoole)
        //Ok(u16::from_le_bytes(rx_buf))
        Register::<ChannelDiag>::reset()
    }
}

pub struct TLE8108EM {
    spidev: Spidev,
    modes: Register<ChannelMode>,
    diags: Register<ChannelDiag>,
}
impl TLE8108EM {
    pub fn new(path: &str) -> Self {
        let mut spidev = Spidev::open(path).unwrap();
        let options = SpidevOptions::new()
            //.bits_per_word(8)
            .max_speed_hz(TLE8108EM_SPI_SCLK_HZ)
            .mode(TLE8108EM_SPI_MODE)
            .build();
        spidev.configure(&options).unwrap();
        Self {
            spidev,
            modes: Register::<ChannelMode>::reset(),
            diags: Register::<ChannelDiag>::reset(),
        }
    }
    pub fn set_channel(&mut self, channel: Channel, mode: ChannelMode) -> &mut Self {
        self.modes[channel] = mode;
        return self;
    }
    pub fn reset_channels(&mut self) -> &mut Self {
        self.modes = Register::<ChannelMode>::reset();
        return self;
    }
    pub fn update(&mut self) -> io::Result<()> {
        let response = transfer(&mut self.spidev, self.modes.pack())?;
        self.diags = response.unpack();
        Ok(())
    }
}

fn transfer(spi: &mut Spidev, payload: BinaryRegister) -> io::Result<BinaryRegister> {
    trace!("SPI TX: 0x{:X}{:X}", payload[1], payload[0]);
    let mut response = [0; 2];
    let mut transfer = SpidevTransfer::read_write(&payload, &mut response);
    spi.transfer(&mut transfer)?;
    trace!("SPI RX: 0x{:X}{:X}", response[1], response[0]);
    Ok(response)
}

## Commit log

2022-10-11 First attempt at shared state + better error handling (#6)
    * Hardware driver
    * CLI
    * First attempt at shared state + error handling
    [main.rs]
2022-10-21 Mode switching API (#7)
2022-10-23 Raspberry pi cross compilation support (#9)
2022-10-25 Hardware driver (#10)
2022-11-07 True mock driver + docker driver (#18)
2022-11-28 Analytics backend fixes (#34)
    [main.rs]
2022-12-03 Integrated Modification Page (#38)
    * Initial Commit. Endpoints connected. CSS and spanner left.
    * Refactored and updated Modication Table
    * MVP DNS message modification (#28)
    * Refactor DNS attack (#29)
    * Install + Uninstall scripts (#30)
    * Logging toggle (#31)
    * Final DNS log format (#32)
    * Test harness fixes (#33)
    * Analytics backend fixes (#34)
    * Frontend install script + wifi AP mode (#35)
    * API bugfixes (#36)
    * Integrated Modification Table
    * Implemented Collaspsible Logs Table
    * Integrated Logs to the device
    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
2022-12-27 Added electrical schematics/boardview (#54)
    [BOM.csv, switching_board.SchDoc]
2022-12-28 Mechanical (#55)
    [case.stl, insert.stl, lid.stl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]
